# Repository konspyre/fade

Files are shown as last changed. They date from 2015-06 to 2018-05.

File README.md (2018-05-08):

## fade - A fancier attempt at a dedicated volume control

### Work in progress

This is a generalized development board for V-USB, using the ATTiny85 without a
crystal.

The board files are free for re-use, modification, and manufacture without
restriction.

The repository here contains KiCAD sources (schematic/board files),
basic V-USB code that implements a key-based HID media controller
(with modifications for this board) and a Bill of Materials listing.

***Note***: The VID/PID need to be properly defined before using this board in
production. This should be your own VID/PID, or from a source such as
[http://pid.codes](http://pid.codes).

## Usable pins

| Pin on ATTiny | Goes to | Connected to ISP as
|---|---|---|
| PB0 | Pin 2 on connector | MOSI
| PB3 | Pin 3 on connector | Not Connected
| PB4 | Pin 4 on connector | Not Connected

## Bill of Materials

#### This builds one board

| Quantity | Placement | Description | Digikey Part Number | Notes |
|---|---|---|---|---|
|1|Center, with corner dot aligned to silkscreened dot |ATTiny85 (PDIP)|ATTINY85-20PU-ND|ATTiny in PDIP format
|1|2.2K|2.2K ohm resistor|1276-5070-1-ND|Pull-up resistor for D- (0603 imperial)
|1|4.7K|4.7k ohm resistor|P4.7KGCT-ND|Pull-up resistor for AVR RESET line (0603 imperial)
|1|C1|10uF 16V 20% X6S capacitor|490-10499-1-ND|Bypass at USB input (0805 imperial)
|1|C2|0.1uF capacitor|490-1532-1-ND|Just buy a bunch. Singles are expensive! (0603 imperial)
|1|USB box at board edge (4 pads with plated through-holes)|USB connector|WM17116CT-ND|Mini USB-B
|2|68R|68 ohm resistor|311-68GRCT-ND|USB data terminators (0603 imperial)
|2|D1+D2 with striped side opposite board markings|3.6V Zener diode|BZT52C3V6-E3-08-ND|SOD123 format

#### Optional components

| Quantity | Placement | Description | Digikey Part Number | Notes
|---|---|---|---|---|
|1|ATTiny footprint (aligned with the U silk)|8 pin DIP socket|A120347-ND|The older socket used in prototypes was P/N 390261-2 and was discontinued
|1|330R|330 ohm resistor|1276-5050-1-ND|Current limiting resistor for PWR LED
|1|Next to 330R (+ - silk)|Power LED|475-2512-1-ND|Red LED 0603 imperial
|1|+5V / GND silk-screened box|Right angle 1x5 female header|S5480-ND|For connecting to carrier boards (female header)
|1|+5V / GND silkscreened box|Right angle 1x5 male header|S1121E-05-ND|For connecting to carrier boards (male header)
|1|2x3 header|6 pin AVR ISP header|3M9459-ND|For flashing the ATTiny85

## Flashing firmware

Ensure that you have all the avr tools necessary to compile the firmware. On
Debian/Ubuntu based systems the dependencies are:

    sudo apt-get install -y build-essential gcc-avr gdb-avr binutils-avr avr-libc avrdude

In the firmware directory (depending on how your system permissions are setup pre-pending `sudo` may be necessary):

    cd firmware
    make hex
    make program
    make fuse

## Fuses (important)

These must be programmed, otherwise your board will not
enumerate with the host.

    avrdude -c buspirate -p attiny85 -P /dev/ttyUSB0
     -U hfuse:w:0xdd:m -U lfuse:w:0xe1:m

## Schematic

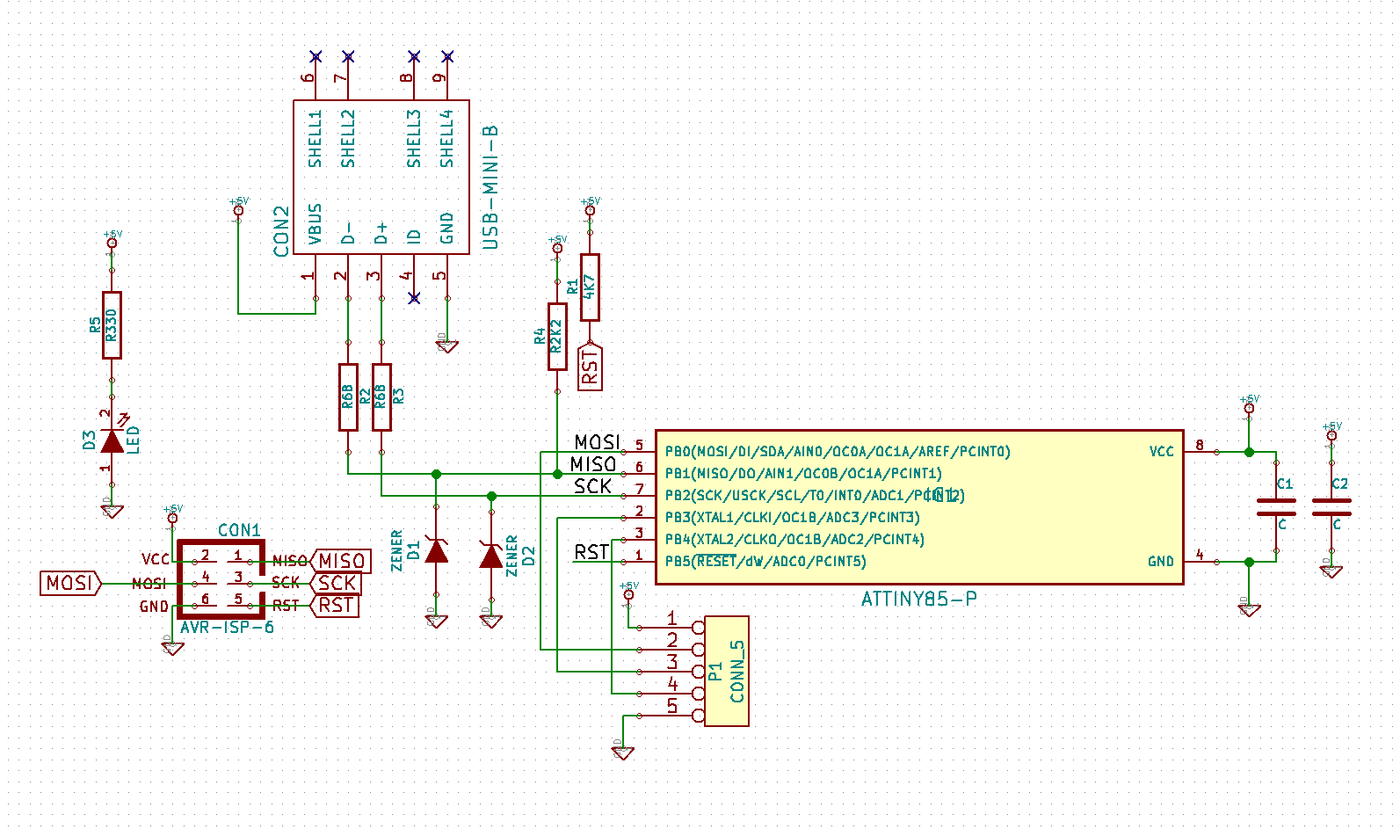
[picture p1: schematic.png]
board schematic


#### License

Board files, schematic and PCB are **CC0 1.0 Universal**.

V-USB firmware and accompanying source code is **GPL 2.0 licensed**.

For more information and full license text, see the LICENSE.md file in this
repository.

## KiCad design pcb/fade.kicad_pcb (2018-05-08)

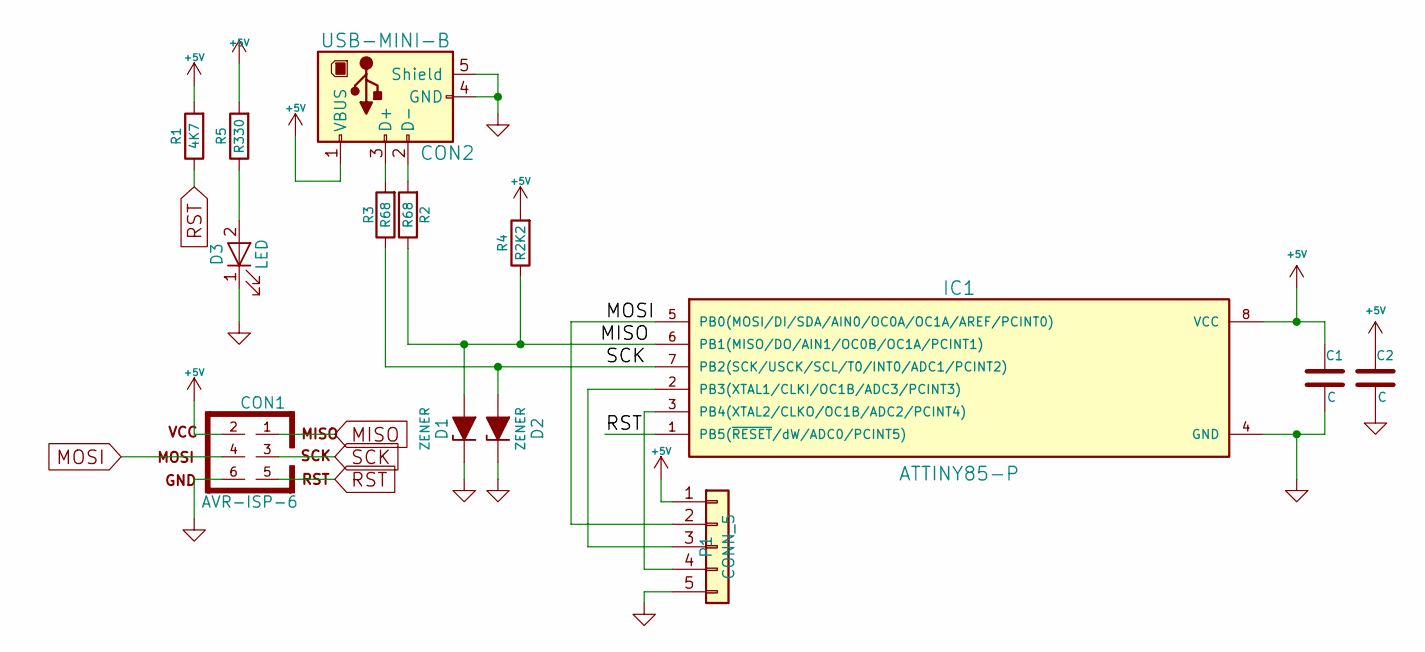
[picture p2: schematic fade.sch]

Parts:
C1, C2: C
CON1: AVR-ISP-6
CON2: USB-MINI-B; USB_MINI_B_SMT
D1, D2: ZENER
D3: LED
IC1: ATTINY85-P; DIP8
P1: CONN_5
R1: 4K7
R2, R3: R68
R4: R2K2
R5: R330

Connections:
+5V: C1.1, C2.1, CON1.2, CON2.1 (VBUS), IC1.8 (VCC), P1.1, R1.2, R4.2, R5.2
GND: C1.2, C2.2, CON1.6, CON2.4 (GND), CON2.5 (Shield), D1.1 (K), D2.1 (K), D3.1 (K), IC1.4 (GND), P1.5
MISO: CON1.1, D1.2 (A), IC1.6 (PB1(MISO/DO/AIN1/OC0B/OC1A/PCINT1)), R2.1, R4.1
MOSI: CON1.4, IC1.5 (PB0(MOSI/DI/SDA/AIN0/OC0A/OC1A/AREF/PCI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), P1.2
unnamed: CON2.2 (D-), R2.2
unnamed: CON2.3 (D+), R3.2
unnamed: D3.2 (A), R5.1
unnamed: IC1.2 (PB3(XTAL1/CLKI/OC1B/ADC3/PCINT3)), P1.3
unnamed: IC1.3 (PB4(XTAL2/CLKO/OC1B/ADC2/PCINT4)), P1.4
RST: CON1.5, IC1.1 (PB5(~RESET~/dW/ADC0/PCINT5)), R1.1
SCK: CON1.3, D2.2 (A), IC1.7 (PB2(SCK/USCK/SCL/T0/INT0/ADC1/PCINT2)), R3.1

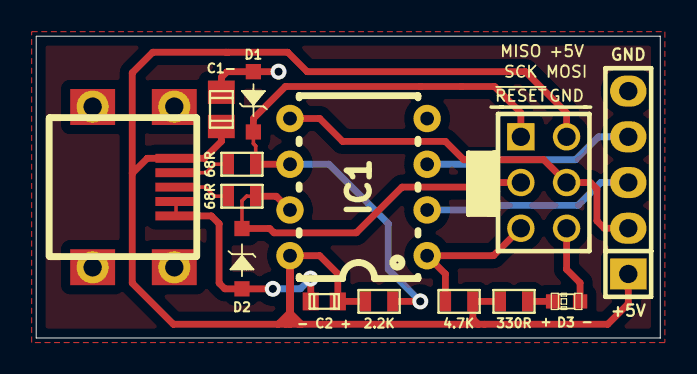
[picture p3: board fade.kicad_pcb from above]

Board: 2 copper layers, 34.7 x 16.8 mm, 14 parts (0 on the bottom side), 11 nets.

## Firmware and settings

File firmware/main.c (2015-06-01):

/*
//
// V-USB keyboard (multimedia-only for now) using an ATTiny85
// GPL2 (V-USB constrained)
//
// Designed around the ATtiny85 with some code and documentation
// derived from Adafruit's IRKey and other places as
// noted.
//
// Hardware buttons present in this design:
// PB0 - #1
// PB3 - #2
// PB4 - #3
//
// The ATTiny85's internal pull-ups are connected to these pins.
//
*/

#include <avr/io.h>
#include <avr/wdt.h>
#include <avr/interrupt.h>
#include <avr/pgmspace.h>
#include <avr/eeprom.h>
#include <avr/pgmspace.h>

#include <util/delay.h>

#include "usbconfig.h"
#include "usbdrv/usbdrv.h"

#define KEY_VOL_UP   PB0 // PCB: Pin 1
#define KEY_VOL_MUTE PB3 // PCB: Pin 2
#define KEY_VOL_DOWN PB4 // PCB: Pin 3

/*
// Keycodes issued by this code:
// Reference: p.77 & p.78 of Hut1_12v2.pdf
// Mute: 0xE3
// Volume Up: 0xE9
// Volume Down: 0xEA
*/

#define KEYCODE_VOL_UP   0xE9
#define KEYCODE_VOL_MUTE 0xE3
#define KEYCODE_VOL_DOWN 0xEA

#define STATE_WAIT    0
#define STATE_SEND    1
#define STATE_RELEASE 2

/*
// Custom descriptor stored in flash memory
// See: http://vusb.wikidot.com/examples
// Descriptors can be found in HID1_11.pdf - "Device Class Definition
// for Human Interface Devices (HID)"
// Appendix B: Boot Interface Descriptors
// USB.org also provides a Windows only tool that can be used to generate
// descriptors:
// http://www.usb.org/developers/hidpage/
//
// Frank's tutorial on how to build these:
// http://eleccelerator.com/tutorial-about-usb-hid-report-descriptors/
//
// More documentation:
// http://www.usb.org/developers/hidpage/Hut1_12v2.pdf
//
*/

// Derived from the IRKey
const PROGMEM const char usbHidReportDescriptor[USB_CFG_HID_REPORT_DESCRIPTOR_LENGTH] = {
  0x05, 0x0C,           // USAGE_PAGE (Consumer Devices)
  0x09, 0x01,           // USAGE (Consumer Control)
  0xA1, 0x01,           // COLLECTION (Application)
  0x85, 0x01,            //   REPORT_ID
  0x19, 0x00,           //   USAGE_MINIMUM (Unassigned)
  0x2A, 0x3C, 0x02,     //   USAGE_MAXIMUM
  0x15, 0x00,           //   LOGICAL_MINIMUM (0)
  0x26, 0x3C, 0x02,     //   LOGICAL_MAXIMUM
  0x95, 0x08,           //   REPORT_COUNT (1)
  0x75, 0x10,           //   REPORT_SIZE (16)
  0x81, 0x00,           //   INPUT (Data,Ary,Abs)
  0xC0,                 // END_COLLECTION
};

static uchar   reportBuffer[2];
static uchar   idleRate = 500 / 4;   // idleRate is defined in 4ms increments.
                                     // We need 500 ms to satisfy 7.2.4
                                     // HID1_11.pdf
static uint8_t protocolVersion = 0;  // 0 = boot protocol (7.2.6, HID1_11.pdf)

uchar lastKey = 0;

/*
// usbFunctionSetup: Handle incoming responses from the system.
// From: http://vusb.wikidot.com/driver-api (code styling derived from Adafruit IRKey)
*/

USB_PUBLIC uchar usbFunctionSetup(uchar data[8]) {
  usbRequest_t *rq = (void *)data;

  // Reject if not class request
  if((rq->bmRequestType & USBRQ_TYPE_MASK) != USBRQ_TYPE_CLASS) {
      return 0;
  }

  switch(rq->bRequest) {

    case USBRQ_HID_GET_REPORT:
      usbMsgPtr = &reportBuffer;
      return sizeof(reportBuffer);

    case USBRQ_HID_GET_IDLE:
      usbMsgPtr = &idleRate;
      return 1;

    case USBRQ_HID_SET_IDLE:
      idleRate = rq->wValue.bytes[1];
      return 0;

    case USBRQ_HID_GET_PROTOCOL:
      usbMsgPtr = &protocolVersion;
      return 1;

    case USBRQ_HID_SET_PROTOCOL:
      protocolVersion = rq->wValue.bytes[1];
      return 0;

    default:
      return 0;

  }
}

int main() {
    uchar   bounce_timer = 0, state = STATE_WAIT, calibrationValue;

    // Set pins to input
    DDRB &= ~(1 << KEY_VOL_UP);
    DDRB &= ~(1 << KEY_VOL_MUTE);
    DDRB &= ~(1 << KEY_VOL_DOWN);

    // Enable built-in pull-ups on input lines
    PORTB |= (1 << KEY_VOL_UP);
    PORTB |= (1 << KEY_VOL_MUTE);
    PORTB |= (1 << KEY_VOL_DOWN);

    /*
    // Begin re-enumeration in case of a sudden device CPU reset.
    // Reason: The host doesn't know if we crashed or not, and can end up talking
    // to an endpoint that we are no longer on.
    */
    wdt_disable();

    calibrationValue = eeprom_read_byte(0); /* calibration value from last time */
    if(calibrationValue != 0xFF){
        OSCCAL = calibrationValue;
    }

    usbDeviceDisconnect();
    _delay_ms(250);
    usbDeviceConnect();
    usbInit();

    // End re-enumeration (main code path follows)

    while(1) {
      usbPoll();

      // Listen for button pushes
      if(!(PINB & (1<<KEY_VOL_UP))) {
        if(state == STATE_WAIT && bounce_timer == 255) {
            state = STATE_SEND;
            lastKey = KEYCODE_VOL_UP;
            bounce_timer = 0;
        }
      }

      if(!(PINB & (1<<KEY_VOL_MUTE))) {
        if(state == STATE_WAIT && bounce_timer == 255) {
            state = STATE_SEND;
            lastKey = KEYCODE_VOL_MUTE;
            bounce_timer = 0;
        }
      }

      if(!(PINB & (1<<KEY_VOL_DOWN))) {
        if(state == STATE_WAIT && bounce_timer == 255) {
            state = STATE_SEND;
            lastKey = KEYCODE_VOL_DOWN;
            bounce_timer = 0;
        }
      }

      if(bounce_timer < 255) {
        bounce_timer++;
      }

      if(usbInterruptIsReady() && state != STATE_WAIT) {

        switch(state) {
          case STATE_SEND:
            reportBuffer[0] = 0x01;    // Report ID
            reportBuffer[1] = lastKey; // Keycode to send
            state = STATE_RELEASE;
            break;

          case STATE_RELEASE:
            reportBuffer[0] = 0x01;
            reportBuffer[1] = 0;
            state = STATE_WAIT;
            break;

          default:
            state = STATE_WAIT;
        }

        usbSetInterrupt(reportBuffer,sizeof(reportBuffer));
        // Wipe buffer
        reportBuffer[0] = reportBuffer[1] = 0;

      }
  }

  return 0;

}

/*
// Clock tuning on USB reset, dependent on provided frame
// From: http://vusb.wikidot.com/examples
*/
void calibrateOscillator() {
  uchar       step = 128;
  uchar       trialValue = 0, optimumValue;
  int         x, optimumDev, targetValue = (unsigned)(1499 * (double)F_CPU / 10.5e6 + 0.5);
  /* do a binary search: */
  do {
    OSCCAL = trialValue + step;
    x = usbMeasureFrameLength();    /* proportional to current real frequency */
    if(x < targetValue) {             /* frequency still too low */
      trialValue += step;
    }
    step >>= 1;
  } while(step > 0);
  /* We have a precision of +/- 1 for optimum OSCCAL here */
  /* now do a neighborhood search for optimum value */
  optimumValue = trialValue;
  optimumDev = x; /* this is certainly far away from optimum */
  for(OSCCAL = trialValue - 1; OSCCAL <= trialValue + 1; OSCCAL++){
    x = usbMeasureFrameLength() - targetValue;
    if(x < 0)
    x = -x;
    if(x < optimumDev){
      optimumDev = x;
      optimumValue = OSCCAL;
    }
  }

  OSCCAL = optimumValue;

}

void usbEventResetReady(void)
{
  cli();  // usbMeasureFrameLength() counts CPU cycles, so disable interrupts.
  calibrateOscillator();
  sei();
  eeprom_write_byte(0, OSCCAL);   // store the calibrated value in EEPROM
}

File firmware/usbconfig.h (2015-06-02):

/* Name: usbconfig.h
 * Project: V-USB, virtual USB port for Atmel's(r) AVR(r) microcontrollers
 * Author: Christian Starkjohann
 * Creation Date: 2005-04-01
 * Tabsize: 4
 * Copyright: (c) 2005 by OBJECTIVE DEVELOPMENT Software GmbH
 * License: GNU GPL v2 (see License.txt), GNU GPL v3 or proprietary (CommercialLicense.txt)
 */

#ifndef __usbconfig_h_included__
#define __usbconfig_h_included__

/*
General Description:
This file is an example configuration (with inline documentation) for the USB
driver. It configures V-USB for USB D+ connected to Port D bit 2 (which is
also hardware interrupt 0 on many devices) and USB D- to Port D bit 4. You may
wire the lines to any other port, as long as D+ is also wired to INT0 (or any
other hardware interrupt, as long as it is the highest level interrupt, see
section at the end of this file).
+ To create your own usbconfig.h file, copy this file to your project's
+ firmware source directory) and rename it to "usbconfig.h".
+ Then edit it accordingly.
*/

/* ---------------------------- Hardware Config ---------------------------- */

#define USB_CFG_IOPORTNAME      B
/* This is the port where the USB bus is connected. When you configure it to
 * "B", the registers PORTB, PINB and DDRB will be used.
 */
#define USB_CFG_DMINUS_BIT      1
/* This is the bit number in USB_CFG_IOPORT where the USB D- line is connected.
 * This may be any bit in the port.
 */
#define USB_CFG_DPLUS_BIT       2
/* This is the bit number in USB_CFG_IOPORT where the USB D+ line is connected.
 * This may be any bit in the port. Please note that D+ must also be connected
 * to interrupt pin INT0! [You can also use other interrupts, see section
 * "Optional MCU Description" below, or you can connect D- to the interrupt, as
 * it is required if you use the USB_COUNT_SOF feature. If you use D- for the
 * interrupt, the USB interrupt will also be triggered at Start-Of-Frame
 * markers every millisecond.]
 */
#define USB_CFG_CLOCK_KHZ       (F_CPU/1000)
/* Clock rate of the AVR in kHz. Legal values are 12000, 12800, 15000, 16000,
 * 16500, 18000 and 20000. The 12.8 MHz and 16.5 MHz versions of the code
 * require no crystal, they tolerate +/- 1% deviation from the nominal
 * frequency. All other rates require a precision of 2000 ppm and thus a
 * crystal!
 * Since F_CPU should be defined to your actual clock rate anyway, you should
 * not need to modify this setting.
 */
#define USB_CFG_CHECK_CRC       0
/* Define this to 1 if you want that the driver checks integrity of incoming
 * data packets (CRC checks). CRC checks cost quite a bit of code size and are
 * currently only available for 18 MHz crystal clock. You must choose
 * USB_CFG_CLOCK_KHZ = 18000 if you enable this option.
 */

/* ----------------------- Optional Hardware Config ------------------------ */

/* #define USB_CFG_PULLUP_IOPORTNAME   D */
/* If you connect the 1.5k pullup resistor from D- to a port pin instead of
 * V+, you can connect and disconnect the device from firmware by calling
 * the macros usbDeviceConnect() and usbDeviceDisconnect() (see usbdrv.h).
 * This constant defines the port on which the pullup resistor is connected.
 */
/* #define USB_CFG_PULLUP_BIT          4 */
/* This constant defines the bit number in USB_CFG_PULLUP_IOPORT (defined
 * above) where the 1.5k pullup resistor is connected. See description
 * above for details.
 */

/* --------------------------- Functional Range ---------------------------- */
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

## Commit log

2015-06-01 Add schematic, pinout, BOM and license information
2015-06-01 Add PCB and parts
    [dude.kicad_pcb, dude.sch]
2015-06-01 Add 0.1uF capacitor part used on prototypes
2015-06-02 Add USB Product ID 0xFADE on Vendor ID 0x1209 (pid.codes)
    For historical reference, a USB Vendor ID currently costs US $5,000 (2015).
    USB.org accepts Visa, Mastercard, or American Express as payment.
    Thanks to pid.codes for making their donated VID block available to
    projects like these.
2017-05-04 Update BOM
2017-05-04 Update silkscreen
    - Switched naming to "1209: Fade" to reflect VID/PID
    - A placement label for the optional power LED is now present
    [dude.kicad_pcb]
2017-05-04 Add a kicad .gitignore
2017-05-05 Add more helpful silkscreen
    [dude.kicad_pcb]
2018-05-08 Updated fade against KiCad 4.0.7
    Note: DRC is broken, but this board's layout has not changed (it
    should still be fabbable with a desktop PCB milling machine).
    [dude.sch, fade.kicad_pcb, fade.sch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]
